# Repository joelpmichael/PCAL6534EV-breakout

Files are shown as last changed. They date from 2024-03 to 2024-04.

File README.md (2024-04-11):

# PCAL6534EV Breakout

## Contents

- [What?](#what)
- [Why?](#why)
- [How?](#how)
- [Can I buy one?](#can-i-buy-one)
- [Can I make one?](#can-i-make-one)
- [Can I make heaps and sell them?](#can-i-make-heaps-and-sell-them)
- [No really, why?](#no-really-why)
- [Board revision history](#board-revision-history)

## What?

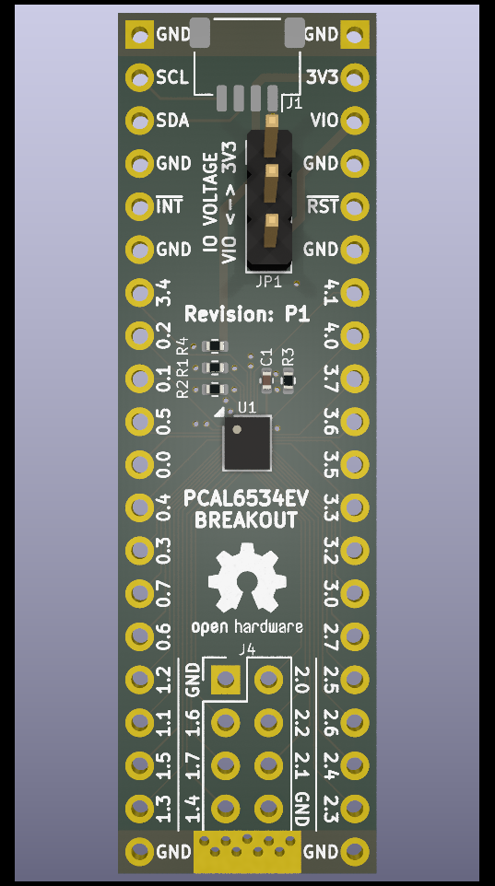
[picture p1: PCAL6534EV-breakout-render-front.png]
3D rendering of PCAL6534EV breakout board front side
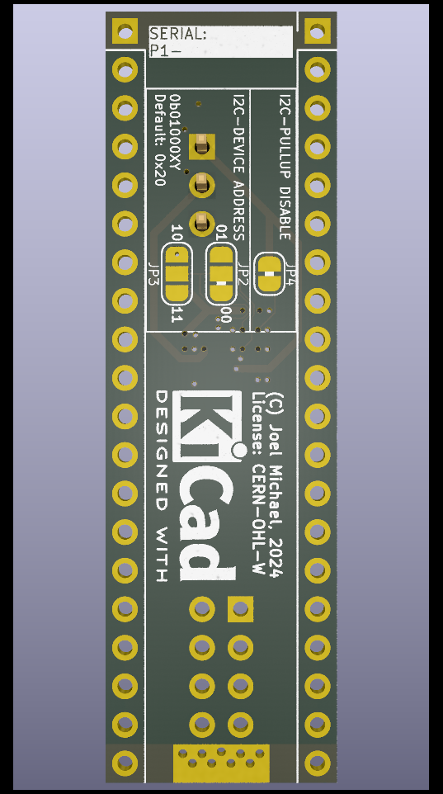
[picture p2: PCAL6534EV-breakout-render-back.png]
3D rendering of PCAL6534EV breakout board back side


This is a breakout board for the [NXP PCAL6534EV I2C GPIO expander](https://www.nxp.com/products/interfaces/ic-spi-i3c-interface-devices/general-purpose-i-o-gpio/ultra-low-voltage-level-translating-34-bit-ic-bus-smbus-i-o-expander:PC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). The board breaks out 32 out of the possible 34 GPIO pins, with 26 of the 32 GPIO pins arranged in a DIP-style layout at 12.7mm column spacing which is perfect for breadboard or protoboard use. There is also a [SparkFun QWIIC-compatible connector](https://www.sparkfun.com/qwiic), for easy connection to other QWIIC-compatible boards.

## Why?

It all started a few years ago, when I was on a holiday in Italy and I found this wonderful little cafe that I stopped at for lunch. I convinced the chef to give me his secret recipe, which he did on one condition: I'm not allowed to tell anybody else until the day I die.

I'm still well and truly alive despite all reports to the contrary, and despite the lack of sleep (#DadLife), so I'm not going to tell you, instead I'm going to make this breakout board instead.

## How?

Please refer to the [PCAL6534EV Datasheet](https://www.nxp.com/docs/en/data-sheet/PCAL6534.pdf) and the [Board Schematic](PCAL6534EV-breakout.pdf) for further details.

- [Connecting](#connecting)
- [Powering](#powering)
- [I2C communication](#i2c-communication)
- [Interrupt and reset](#interrupt-and-reset)
- [GPIO use](#gpio-use)
- [Mounting](#mounting)

### Connecting

Solder the 20-pin headers into each side and slam it into a breadboard! The width is minimised to allow access to 3 pins on each side - wider breakout and prototype boards have always annoyed me by only allowing access to 1 or 2 pins on each side.

Use the QWIIC-compatible connector J1 to connect to your MCU, as the PCAL6534EV is optimised to run at 3.3V. You may run into current supply limits when using the very thin 28AWG wire in QWIIC-compatible cables, as the PCAL6534EV can source up to 450mA or sink up to 500mA of current. If you're driving a lot of LEDs or something, hook up an additional 3.3V power connection to the pin header, and maybe a chonky electrolytic capacitor across 3V3 or VIO.

You can also solder wires directly to the pin headers if needed, or solder the pin headers to a protoboard, or just do what you want I'm not your mum.

At the very bottom edge of the breakout board is an exposed ground plane, designed for you to attach an alligator clip while probing with a multimeter, osciloscope, or logic analyzer.

### Powering

The PCAL6534EV requires 2 power supplies, VDD(i2c) and VDD(p). VDD(i2c) is wired to the 3V3 rail, and must be in the range of 0.8 to 3.6V, allowing you to use lower voltage MCU or FPGA I2C lines. VDD(p) is wired to jumper JP1, and must be in the range of 1.65 to 5.5V. Jumper JP1 selects the source rail of VDD(p), either 3V3 or VIO. When jumper JP1 is set to 3V3, the 3V3 input voltage range is narrowed to 1.65 to 3.6V. When jumper JP1 is set to VIO, the desired IO voltage must be supplied on the VIO pin.

### I2C communication

The PCAL6534EV supports I2C standard-mode at up to 100kHz, fast-mode at up to 400kHz, or fast-mode plus at up to 1000kHz. The breakout board contains 4.7kΩ pull-up resistors from I2C SDA and SCL lines to the 3V3 rail. These pull-up resistors can be disabled by cutting the PCB trace jumper JP4 on the back of the breakout board.

The PCAL6534EV I2C device address is set by connecting the ADDR line to either SDA, SCL, VSS (ground), or VDD(i2c), with a base 7-bit I2C device address of `0b0100000` (`0x20`). The breakout board defaults to the base address `0x20`, and by cutting and bridging PCB jumper pins on JP2 and JP3 can set the device address to `0x20`, `0x21`, `0x22`, or `0x23` according to the following table:

|Jumper|Pins|Address|
|---|----|---|
|JP2|1-2|0x20|
|JP2|2-3|0x21|
|JP3|1-2|0x22|
|JP3|2-3|0x23|

> ⚠️ SDA and SCL pins **ARE NOT** 5V-tolerant!

### Interrupt and reset

The PCAL6534EV contains both an Interrupt (IRQ) line, and a Reset (RST) line. Both lines are active-low. The IRQ output line uses an open-drain driver, and the breakout board contains a 10kΩ pull-up resistor to VDD(i2c) because most likely you'll be using the IRQ signal on the same MCU that the I2C controller is running on. If you really really really REALLY need to change this, you can remove R4 and connect another pull-up resistor between R4 pad 1 (closest to JP4) and VIO, ensuring that VIO is limited to 3.3V.

The Reset input line is an active-low input, and the breakout board contains a a 10kΩ pull-up resistor to VDD(i2c) because most likely you'll be supplying the Reset signal from the same MCU that the I2C controller is running on, or you've wired the Reset line to an external momentary switch and you don't care about the voltage. If you're using a momentary switch, add a 0.1µF capacitor in parallel to the switch for a hardware debouncer and noise filter. It is safe to leave the Reset line disconnected from the breakout board.

> ⚠️ Interrupt and Reset pins **ARE NOT** 5V-tolerant!

### GPIO use

It's a... uh... low-speed GPIO? Just use them, the default PCAL6534EV configuration should work for most cases! All the GPIO pins are 5V-tolerant, and will even produce 5V output if you're using 5V on VIO, so feel free to hook them up to your old MEGA328P-based Arduinos and do voltage level translation. You can even drive a LOT of LEDs directly from the GPIO pins - every pin is recommended to source 10mA or sink 25mA of current, with a combined total of 450mA of sourcing current and 500mA of sinking current.

For advanced use-cases, such as enabling internal 100kΩ pull-up or pull-down resistors, switching between push-pull or open-drain output mode, enabling interrupt generation, enabling debouncing filters, or reducing the drive strength to limit GPIO switching noise, please refer to the datasheet and the example source code.

> ✔️ GPIO pins **ARE** 5V-tolerant!

### Mounting

Due to asthetics and space constraints there isn't enough room for a full-size mounting hole, however in the middle of the OSHW logo there is a 1mm pilot hole that you can use to drill a mounting hole. Ideal? No. Pragmatic? Yes. 

Personally I wouldn't drill a hole larger than 3mm, which will allow you to use a M3 fastener, but you should be able drill up to a 5mm hole without hitting traces. If using metal fasteners, use nylon washers to avoid damage to traces by screw heads.

## Can I buy one?

Sure! Once I've got enough requests for a small batch run I'll send off an order. I test every single board to make sure it's fully functional before shipping.

## Can I make one?

Sure, why not? The board is designed to be manufactured using JLCPCB's 6-layer fabrication constraints as at March 2024 by using budget-size 50mm maximum dimension, budget 0.3mm drill size, 0.8mm thickness, 1oz outer copper, 0.5oz inner copper, and the budget (but surprisingly good) JLC06081H-1080A stackup. It currently does not meet OSHPARK fabrication constraints, as the trace and space minimum of 0.09mm is smaller than the required 0.1mm and there is some via-in-pad use which is currently unsupported.

## Can I make heaps and sell them?

Technically yes, but I'd love it if you gave me a cut in exchange for the testing system that I've developed.

## No really, why?

I wanted to use this GPIO expander in another project, and making a breakout board was probably the best way to verify if my layout hacks would work at all.

Also, shits and giggles: seeing who's both willing and able to manufacture the boards.

## Board Revision History

- [P1](#p1-prototype-1)

### P1: Prototype 1

First prototype, for testing if this even works at all

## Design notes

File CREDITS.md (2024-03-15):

# Credits And Thanks

Thank you to the following people for their help in bringing this idiot idea to life!

## Inspiration and hacks

### Andrew Zonenberg ([Fediverse](https://ioc.exchange/@azonenberg)) ([GitHub](https://github.com/azonenberg))

Thank you for getting me interested in doing my first FPGA design, which lead to me looking at the PCAL6534EV in the first place for power supply sequencing (this is a hint of my next project). Your mention of squashing BGA lands is the hack I'm trying here so I don't need to spend crazy amounts of money on 0.1mm laser vias.

## Prototype reviewers

(none yet)

## Prototype testers

(none yet)

## Contributors

(none yet)

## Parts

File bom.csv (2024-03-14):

Reference | Value | Datasheet | Footprint | Qty | DNP
C1 | 0.22u | ~ | Capacitor_SMD:C_0402_1005Metric | 1
J1 | SM04B-SRSS-TB | ~ | Connector_JST:JST_SH_SM04B-SRSS-TB_1x04-1MP_P1.00mm_Horizontal | 1
J2,J3 | Conn_01x20 | ~ | Connector_PinHeader_2.54mm:PinHeader_1x20_P2.54mm_Vertical | 2 | DNP
J4 | Conn_02x04_Odd_Even | ~ | Connector_PinHeader_2.54mm:PinHeader_2x04_P2.54mm_Vertical | 1 | DNP
JP1 | Jumper_3_Bridged12 | ~ | Connector_PinHeader_2.54mm:PinHeader_1x03_P2.54mm_Vertical | 1
R1,R2 | 4.7k | ~ | Resistor_SMD:R_0402_1005Metric | 2
R3,R4 | 10k | ~ | Resistor_SMD:R_0402_1005Metric | 2
U1 | PCAL6534EV | https://www.nxp.com/docs/en/data-sheet/PCAL6534.pdf | Package_BGA:NXP_VFBGA-42_2.6x3mm_Layout6x7_P0.4mm_Ball0.25mm_Pad0.24mm | 1

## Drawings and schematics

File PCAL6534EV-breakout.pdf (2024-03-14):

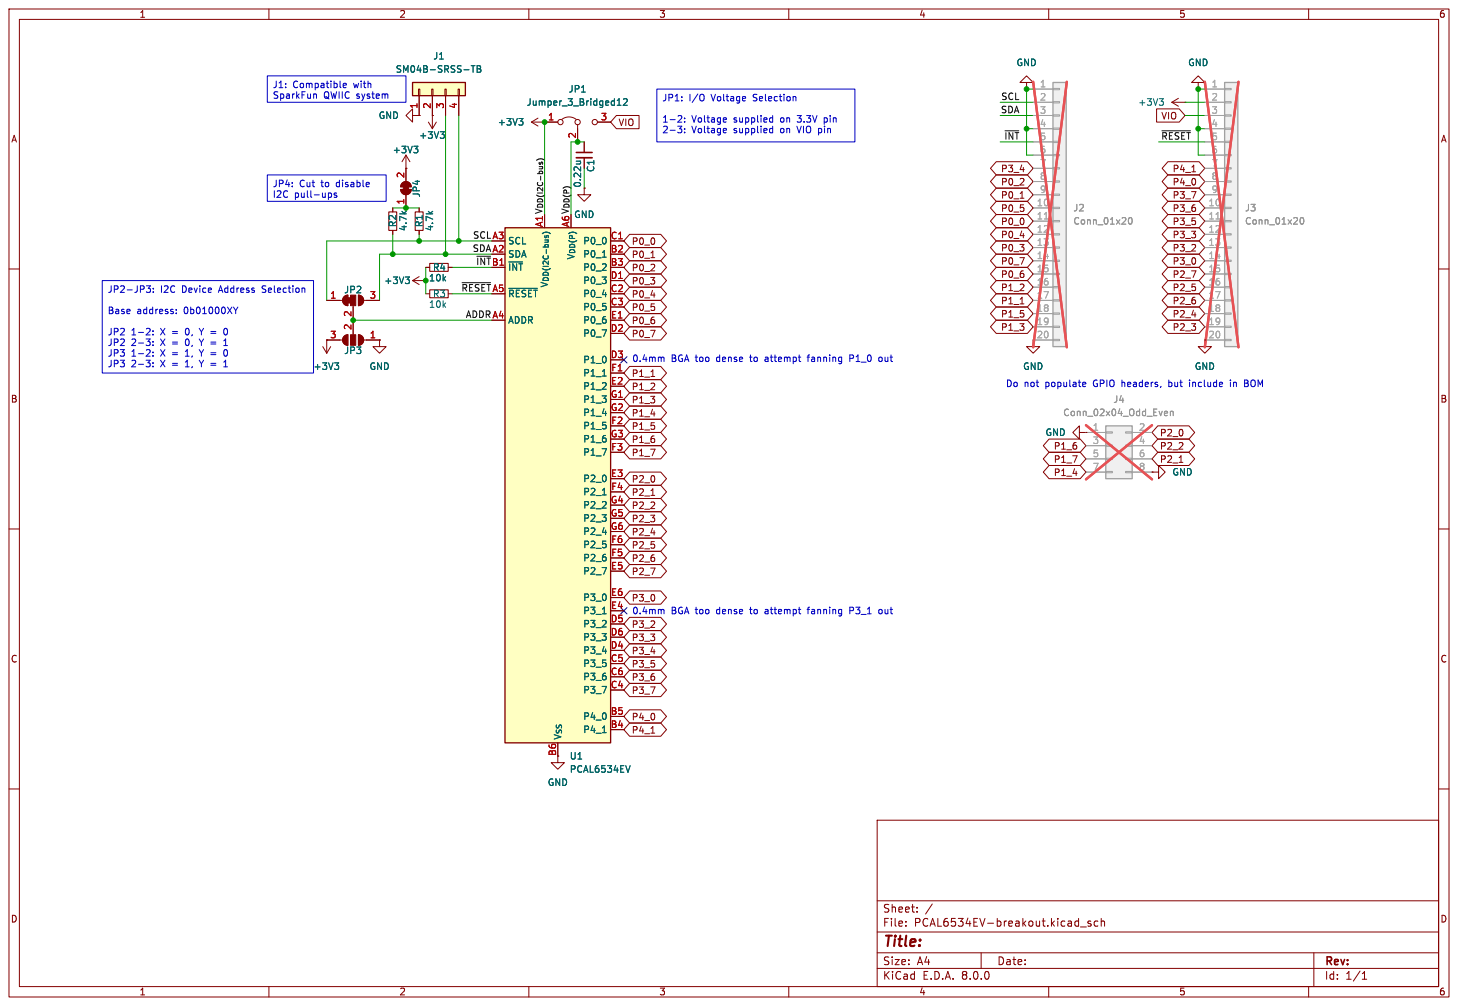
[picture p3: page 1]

Id: 1/1 Title: File: PCAL6534EV-breakout.kicad_sch Sheet: /

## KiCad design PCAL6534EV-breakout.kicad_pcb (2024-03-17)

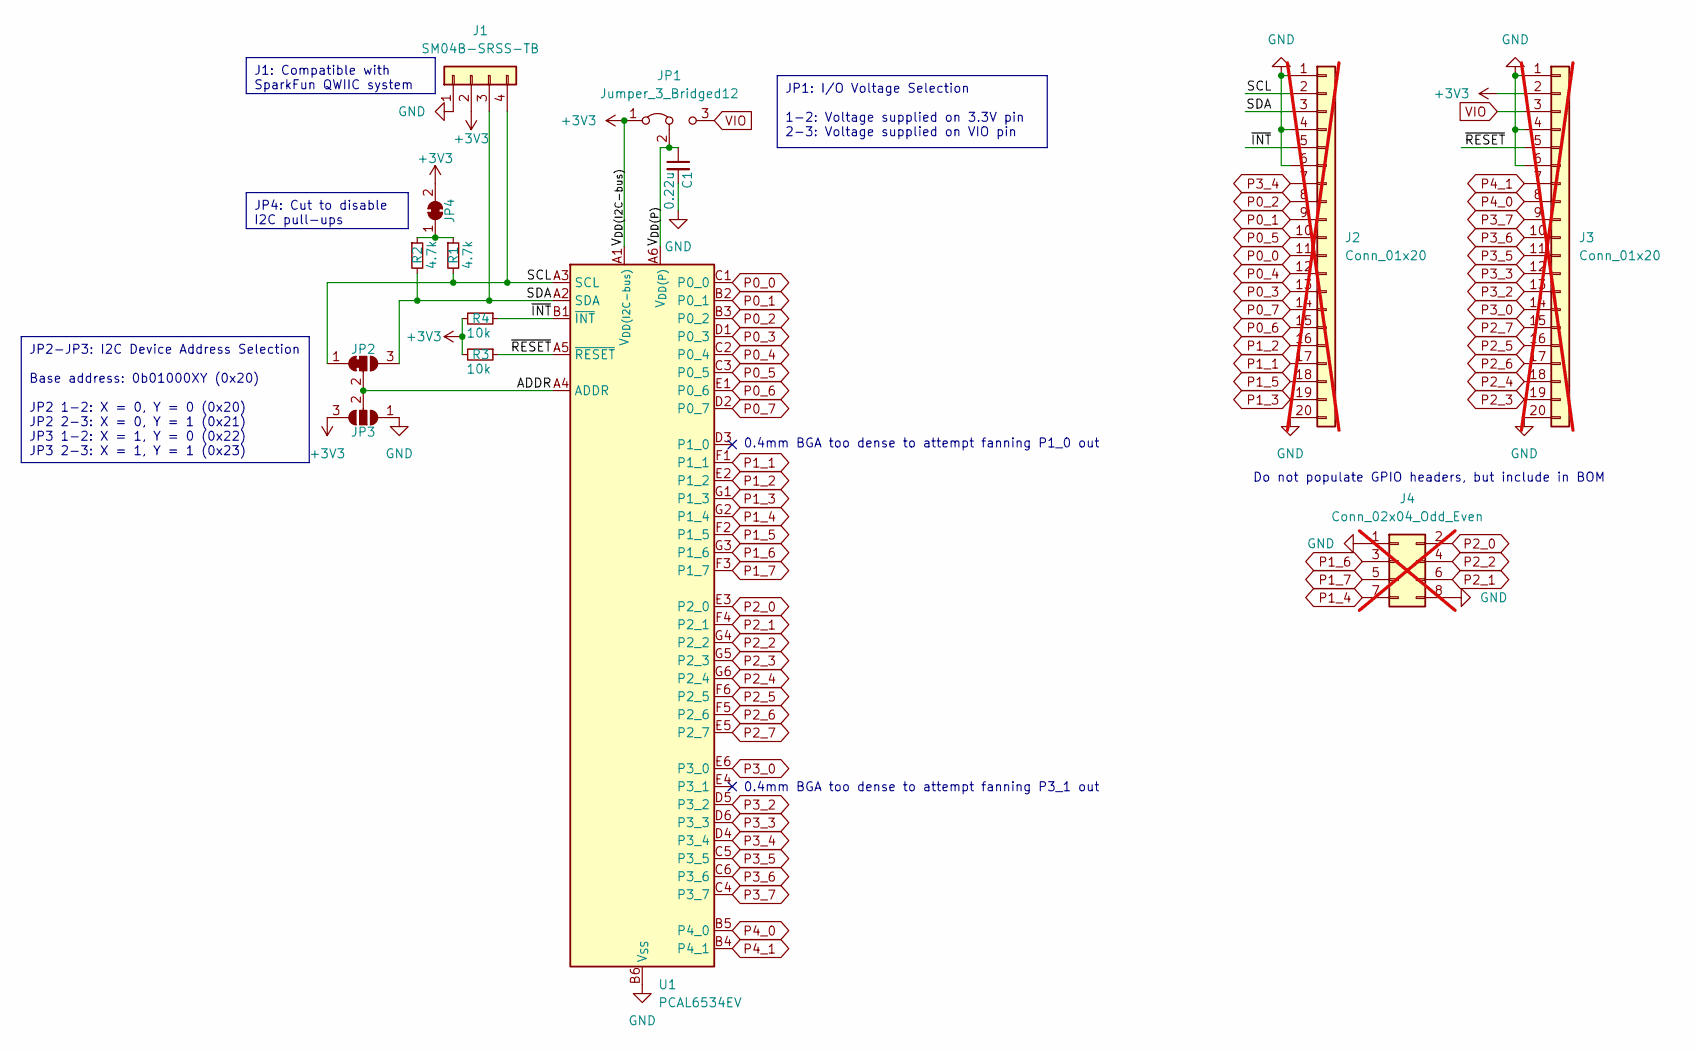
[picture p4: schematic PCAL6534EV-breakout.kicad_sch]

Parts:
C1: 0.22u; C_0402_1005Metric
J1: SM04B-SRSS-TB; JST_SH_SM04B-SRSS-TB_1x04-1MP_P1.00mm_Horizontal
J2, J3: Conn_01x20; PinHeader_1x20_P2.54mm_Vertical; not fitted
J4: Conn_02x04_Odd_Even; PinHeader_2x04_P2.54mm_Vertical; not fitted
JP1: Jumper_3_Bridged12; PinHeader_1x03_P2.54mm_Vertical
JP2: SolderJumper_3_Bridged12; SolderJumper-3_P1.3mm_Bridged12_RoundedPad1.0x1.5mm_NumberL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
JP3: SolderJumper_3_Open; SolderJumper-3_P1.3mm_Open_RoundedPad1.0x1.5mm_NumberLabels
JP4: SolderJumper_2_Bridged; SolderJumper-2_P1.3mm_Bridged_RoundedPad1.0x1.5mm
R1, R2: 4.7k; R_0402_1005Metric
R3, R4: 10k; R_0402_1005Metric
U1: PCAL6534EV; NXP_VFBGA-42_2.6x3mm_Layout6x7_P0.4mm_Ball0.25mm_Pad0.24mm

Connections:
+3V3: J1.2, J3.2, JP1.1 (A), JP3.3 (B), JP4.2 (B), R3.2, R4.2, U1.A1 (V_{DD(I2C-bus)})
/ADDR: JP2.2 (C), JP3.2 (C), U1.A4 (ADDR)
/SCL: J1.4, J2.2, JP2.1 (A), R1.2, U1.A3 (SCL)
/SDA: J1.3, J2.3, JP2.3 (B), R2.2, U1.A2 (SDA)
/V_{DD(P)}: C1.1, JP1.2 (C), U1.A6 (V_{DD(P)})
/~INT: J2.5, R4.1, U1.B1 (~INT)
/~RESET: J3.5, R3.1, U1.A5 (~RESET)
GND: C1.2, J1.1, J1.MP, J2.1, J2.4, J2.6, J2.20, J3.1, J3.4, J3.6, J3.20, J4.1, J4.8, JP3.1 (A), U1.B6 (V_{SS})
unnamed: JP4.1 (A), R1.1, R2.1
P0_0: J2.11, U1.C1 (P0_0)
P0_1: J2.9, U1.B2 (P0_1)
P0_2: J2.8, U1.B3 (P0_2)
P0_3: J2.13, U1.D1 (P0_3)
P0_4: J2.12, U1.C2 (P0_4)
P0_5: J2.10, U1.C3 (P0_5)
P0_6: J2.15, U1.E1 (P0_6)
P0_7: J2.14, U1.D2 (P0_7)
P1_1: J2.17, U1.F1 (P1_1)
P1_2: J2.16, U1.E2 (P1_2)
P1_3: J2.19, U1.G1 (P1_3)
P1_4: J4.7, U1.G2 (P1_4)
P1_5: J2.18, U1.F2 (P1_5)
P1_6: J4.3, U1.G3 (P1_6)
P1_7: J4.5, U1.F3 (P1_7)
P2_0: J4.2, U1.E3 (P2_0)
P2_1: J4.6, U1.F4 (P2_1)
P2_2: J4.4, U1.G4 (P2_2)
P2_3: J3.19, U1.G5 (P2_3)
P2_4: J3.18, U1.G6 (P2_4)
P2_5: J3.16, U1.F6 (P2_5)
P2_6: J3.17, U1.F5 (P2_6)
P2_7: J3.15, U1.E5 (P2_7)
P3_0: J3.14, U1.E6 (P3_0)
P3_2: J3.13, U1.D5 (P3_2)
P3_3: J3.12, U1.D6 (P3_3)
P3_4: J2.7, U1.D4 (P3_4)
P3_5: J3.11, U1.C5 (P3_5)
P3_6: J3.10, U1.C6 (P3_6)
P3_7: J3.9, U1.C4 (P3_7)
P4_0: J3.8, U1.B5 (P4_0)
P4_1: J3.7, U1.B4 (P4_1)
VIO: J3.3, JP1.3 (B)

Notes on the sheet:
JP1: I/O Voltage Selection 1-2: Voltage supplied on 3.3V pin 2-3: Voltage supplied on VIO pin
J1: Compatible with SparkFun QWIIC system
JP4: Cut to disable I2C pull-ups
JP2-JP3: I2C Device Address Selection Base address: 0b01000XY (0x20) JP2 1-2: X = 0, Y = 0 (0x20) JP2 2-3: X = 0, Y = 1 (0x21) JP3 1-2: X = 1, Y = 0 (0x22) JP3 2-3: X = 1, Y = 1 (0x23)
0.4mm BGA too dense to attempt fanning P3_1 out
Do not populate GPIO headers, but include in BOM
0.4mm BGA too dense to attempt fanning P1_0 out

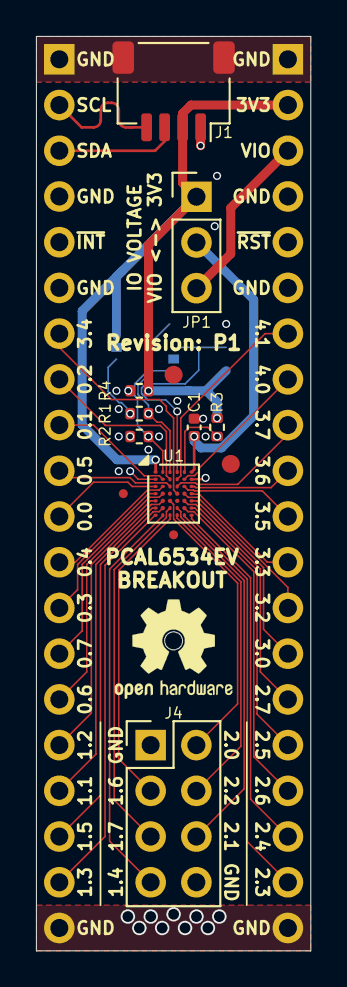
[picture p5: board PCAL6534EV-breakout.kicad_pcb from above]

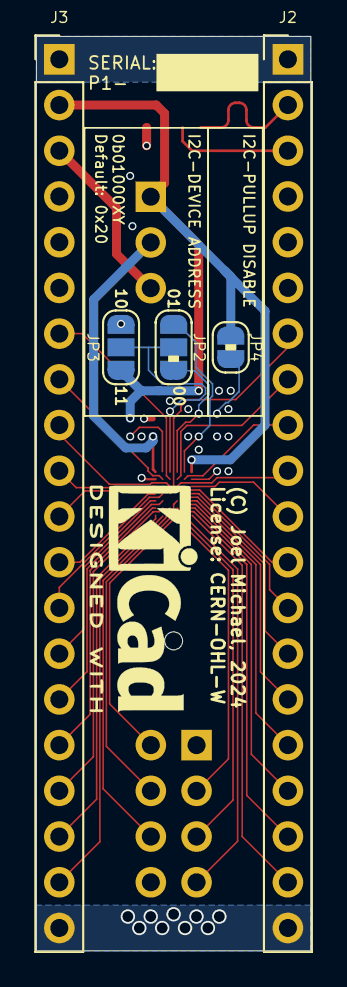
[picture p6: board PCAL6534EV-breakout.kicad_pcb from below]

Board: 6 copper layers, 15.2 x 50.8 mm, 18 parts (5 on the bottom side), 42 nets.

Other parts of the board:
FID1, FID2: Fiducial_0.5mm_Mask1mm
FID3, FID4: Fiducial_1mm_Mask2mm

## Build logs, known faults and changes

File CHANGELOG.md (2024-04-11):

# Change / Development Log

## Hardware prototype 2

### Fixes

* Connect MP pins of J1 to GND strip across the top edge of the board

## Driver release 1

TODO

## Hardware prototype 1

### 5 April 2023

First prototype run of boards arrived. Issue identified where MP on J1 was not connected to the GND strip across the top edge of the board, which would compromise strength of J1 and possibly lead to J1 being ripped off the board under mechanical stress.

### Serial 1

Used a LOT of flux and SnBi low-temperature solder on a hotplate. Solder reflow worked ok (not great, but not unusable), but would probably work better using less solder and/or an actual stencil.  Shorts between the following pins:

* P0_0 - P0_3
* P1_2 - P2_0
* P3_0 - P2_5
* P2_7 - P2_6

Pin headers added using SnPb 60/40 solder.

Communication established using Excamera I2Cdriver board. Verified all GPIOs can be changed from hi-z inputs to push-pull outputs. Verified all GPIOs are connected, and show both 3.3V and 0V levels when output level is set. Verified LED using current-sinking on P4_1.

### Serial 2

TODO

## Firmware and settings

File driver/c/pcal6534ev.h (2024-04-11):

/*
 *
 * PCAL6534EV driver - C example
 *
 * Full datasheet at https://www.nxp.com/docs/en/data-sheet/PCAL6534.pdf
 *
 */

// required includes
#include <stddef.h>
#include <stdint.h>

// Common definitions

// Function return codes
typedef enum pcal6534ev_status_e {
    PCAL6534EV_STATUS_OK = 0,
    PCAL6534EV_STATUS_FAIL = 0,
} pcal6534ev_status;

// Register names
typedef enum pcal6534ev_register_e {
    PCAL6534EV_REG_INPUT_PORT_0 = 0x00,
    PCAL6534EV_REG_INPUT_PORT_1 = 0x01,
    PCAL6534EV_REG_INPUT_PORT_2 = 0x02,
    PCAL6534EV_REG_INPUT_PORT_3 = 0x03,
    PCAL6534EV_REG_INPUT_PORT_4 = 0x04,

    PCAL6534EV_REG_OUTPUT_PORT_0 = 0x05,
    PCAL6534EV_REG_OUTPUT_PORT_1 = 0x06,
    PCAL6534EV_REG_OUTPUT_PORT_2 = 0x07,
    PCAL6534EV_REG_OUTPUT_PORT_3 = 0x08,
    PCAL6534EV_REG_OUTPUT_PORT_4 = 0x09,

    PCAL6534EV_REG_POLINV_PORT_0 = 0x0A,
    PCAL6534EV_REG_POLINV_PORT_1 = 0x0B,
    PCAL6534EV_REG_POLINV_PORT_2 = 0x0C,
    PCAL6534EV_REG_POLINV_PORT_3 = 0x0D,
    PCAL6534EV_REG_POLINV_PORT_4 = 0x0E,

    PCAL6534EV_REG_CONFIG_PORT_0 = 0x0F,
    PCAL6534EV_REG_CONFIG_PORT_1 = 0x10,
    PCAL6534EV_REG_CONFIG_PORT_2 = 0x11,
    PCAL6534EV_REG_CONFIG_PORT_3 = 0x12,
    PCAL6534EV_REG_CONFIG_PORT_4 = 0x13,

    PCAL6534EV_REG_DRIVE_PORT_0A = 0x30,
    PCAL6534EV_REG_DRIVE_PORT_0B = 0x31,
    PCAL6534EV_REG_DRIVE_PORT_1A = 0x32,
    PCAL6534EV_REG_DRIVE_PORT_1B = 0x33,
    PCAL6534EV_REG_DRIVE_PORT_2A = 0x34,
    PCAL6534EV_REG_DRIVE_PORT_2B = 0x35,
    PCAL6534EV_REG_DRIVE_PORT_3A = 0x36,
    PCAL6534EV_REG_DRIVE_PORT_3B = 0x37,
    PCAL6534EV_REG_DRIVE_PORT_4A = 0x38,

    PCAL6534EV_REG_ILATCH_PORT_0 = 0x3A,
    PCAL6534EV_REG_ILATCH_PORT_1 = 0x3B,
    PCAL6534EV_REG_ILATCH_PORT_2 = 0x3C,
    PCAL6534EV_REG_ILATCH_PORT_3 = 0x3D,
    PCAL6534EV_REG_ILATCH_PORT_4 = 0x3E,

    PCAL6534EV_REG_PULLEN_PORT_0 = 0x3F,
    PCAL6534EV_REG_PULLEN_PORT_1 = 0x40,
    PCAL6534EV_REG_PULLEN_PORT_2 = 0x41,
    PCAL6534EV_REG_PULLEN_PORT_3 = 0x42,
    PCAL6534EV_REG_PULLEN_PORT_4 = 0x43,

    PCAL6534EV_REG_PULLDIR_PORT_0 = 0x44,
    PCAL6534EV_REG_PULLDIR_PORT_1 = 0x45,
    PCAL6534EV_REG_PULLDIR_PORT_2 = 0x46,
    PCAL6534EV_REG_PULLDIR_PORT_3 = 0x47,
    PCAL6534EV_REG_PULLDIR_PORT_4 = 0x48,

    PCAL6534EV_REG_IMASK_PORT_0 = 0x49,
    PCAL6534EV_REG_IMASK_PORT_1 = 0x4A,
    PCAL6534EV_REG_IMASK_PORT_2 = 0x4B,
    PCAL6534EV_REG_IMASK_PORT_3 = 0x4C,
    PCAL6534EV_REG_IMASK_PORT_4 = 0x4D,

    PCAL6534EV_REG_ISTAT_PORT_0 = 0x4E,
    PCAL6534EV_REG_ISTAT_PORT_1 = 0x4F,
    PCAL6534EV_REG_ISTAT_PORT_2 = 0x50,
    PCAL6534EV_REG_ISTAT_PORT_3 = 0x51,
    PCAL6534EV_REG_ISTAT_PORT_4 = 0x52,

    PCAL6534EV_REG_OUT_PORT_CFG = 0x53,

    PCAL6534EV_REG_IEDGE_PORT_0A = 0x54,
    PCAL6534EV_REG_IEDGE_PORT_0B = 0x55,
    PCAL6534EV_REG_IEDGE_PORT_1A = 0x56,
    PCAL6534EV_REG_IEDGE_PORT_1B = 0x57,
    PCAL6534EV_REG_IEDGE_PORT_2A = 0x58,
    PCAL6534EV_REG_IEDGE_PORT_2B = 0x59,
    PCAL6534EV_REG_IEDGE_PORT_3A = 0x5A,
    PCAL6534EV_REG_IEDGE_PORT_3B = 0x5B,
    PCAL6534EV_REG_IEDGE_PORT_4A = 0x5C,

    PCAL6534EV_REG_ICLR_PORT_0 = 0x5E,
    PCAL6534EV_REG_ICLR_PORT_1 = 0x5F,
    PCAL6534EV_REG_ICLR_PORT_2 = 0x60,
    PCAL6534EV_REG_ICLR_PORT_3 = 0x61,
    PCAL6534EV_REG_ICLR_PORT_4 = 0x62,

    PCAL6534EV_REG_INPUT_STAT_PORT_0 = 0x63,
    PCAL6534EV_REG_INPUT_STAT_PORT_1 = 0x64,
    PCAL6534EV_REG_INPUT_STAT_PORT_2 = 0x65,
    PCAL6534EV_REG_INPUT_STAT_PORT_3 = 0x66,
    PCAL6534EV_REG_INPUT_STAT_PORT_4 = 0x67,

    PCAL6534EV_REG_OUT_PIN_PORT_0_CFG = 0x68,
    PCAL6534EV_REG_OUT_PIN_PORT_1_CFG = 0x69,
    PCAL6534EV_REG_OUT_PIN_PORT_2_CFG = 0x6A,
    PCAL6534EV_REG_OUT_PIN_PORT_3_CFG = 0x6B,
    PCAL6534EV_REG_OUT_PIN_PORT_4_CFG = 0x6C,

    PCAL6534EV_REG_DEBOUNCE_ENABLE_PORT_0 = 0x6D,
    PCAL6534EV_REG_DEBOUNCE_ENABLE_PORT_1 = 0x6E,
    PCAL6534EV_REG_DEBOUNCE_COUNT = 0x6F,
} pcal6534ev_register;

// Port names
typedef enum pcal6534ev_port_e {
    PCAL6534EV_PORT_0 = 0,
    PCAL6534EV_PORT_1 = 1,
    PCAL6534EV_PORT_2 = 2,
    PCAL6534EV_PORT_3 = 3,
    PCAL6534EV_PORT_4 = 4,
} pcal6534ev_port;
#define PCAL6534EV_PORT_COUNT 5

// Pin names
typedef enum pcal6534ev_port_pin_e {
    PCAL6534EV_PORT_PIN_0 = 1 << 0,
    PCAL6534EV_PORT_PIN_1 = 1 << 1,
    PCAL6534EV_PORT_PIN_2 = 1 << 2,
    PCAL6534EV_PORT_PIN_3 = 1 << 3,
    PCAL6534EV_PORT_PIN_4 = 1 << 4,
    PCAL6534EV_PORT_PIN_5 = 1 << 5,
    PCAL6534EV_PORT_PIN_6 = 1 << 6,
    PCAL6534EV_PORT_PIN_7 = 1 << 7,
} pcal6534ev_port_pin;
#define PCAL6534EV_PORT_PIN_COUNT 8

// Pin levels
typedef enum pcal6534ev_pin_level_e {
    PCAL6534EV_PIN_LEVEL_LOW = 0,
    PCAL6534EV_PIN_LEVEL_HIGH = 1,
} pcal6534ev_pin_level;

// Pin mode configuration - input (hi-z) or output (push-pull/open-drain)
// All pins are configured as input (hi-z) by default
typedef enum pcal6534ev_pin_mode_e {
    PCAL6534EV_PIN_MODE_OUTPUT = 0,
    PCAL6534EV_PIN_MODE_INPUT = 1,
} pcal6534ev_pin_mode;

// Output pin configuration
typedef enum pcal6534ev_pin_output_mode_e {
    PCAL6534EV_PIN_OUTPUT_MODE_PUSHPULL_NOPULL = 0b00,
    PCAL6534EV_PIN_OUTPUT_MODE_OPENDRAIN = 0b01,
    PCAL6534EV_PIN_OUTPUT_MODE_PUSHPULL_PULLDOWN = 0b10,
    PCAL6534EV_PIN_OUTPUT_MODE_PUSHPULL_PULLUP = 0b11,
} pcal6534ev_pin_output_mode;

// Output pin drive strength
typedef enum pcal6534ev_pin_output_drive_e {
    PCAL6534EV_PIN_OUTPUT_DRIVE_25 = 0b00,
    PCAL6534EV_PIN_OUTPUT_DRIVE_50 = 0b01,
    PCAL6534EV_PIN_OUTPUT_DRIVE_75 = 0b10,
    PCAL6534EV_PIN_OUTPUT_DRIVE_100 = 0b11,
} pcal6534ev_pin_output_drive;

// Input pin configuration

typedef enum pcal6534ev_i2c_address_e {
    I2C_GENERAL_CALL = 0x00,

    // Device Addresses: lower 7 bits
    // Suitable for MCU SDKs that expect I2C device address in the lower 7 bits (eg MCP)
    I2C_DEVICE_ID_L = 0xFE >> 1,
    PCAL6534EV_ADDR_00_L = 0x40 >> 1,
    PCAL6534EV_ADDR_01_L = 0x42 >> 1,
    PCAL6534EV_ADDR_10_L = 0x44 >> 1,
    PCAL6534EV_ADDR_11_L = 0x46 >> 1,

    // Device Addresses: upper 7 bits
    // Suitable for MCU SDKs that expect I2C device address in the upper 7 bits (eg STM32)
    I2C_DEVICE_ID_H = 0xFE,
    PCAL6534EV_ADDR_00_H = 0x40,
    PCAL6534EV_ADDR_01_H = 0x42,
    PCAL6534EV_ADDR_10_H = 0x44,
    PCAL6534EV_ADDR_11_H = 0x46,
} pcal6534ev_i2c_address;

// Device address aliases

// For ease of use when the ADDR pin is connected to a known address-set pin
#define PCAL6534EV_ADDR_SCL_L PCAL6534EV_ADDR_00_L
#define PCAL6534EV_ADDR_SDA_L PCAL6534EV_ADDR_10_L
#define PCAL6534EV_ADDR_VSS_L PCAL6534EV_ADDR_01_L
#define PCAL6534EV_ADDR_VDD_L PCAL6534EV_ADDR_11_L
#define PCAL6534EV_ADDR_SCL_H PCAL6534EV_ADDR_00_H
#define PCAL6534EV_ADDR_SDA_H PCAL6534EV_ADDR_10_H
#define PCAL6534EV_ADDR_VSS_H PCAL6534EV_ADDR_01_H
#define PCAL6534EV_ADDR_VDD_H PCAL6534EV_ADDR_11_H
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

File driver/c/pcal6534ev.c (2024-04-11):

/*
 *
 * PCAL6534EV driver - C example
 *
 * Full datasheet at https://www.nxp.com/docs/en/data-sheet/PCAL6534.pdf
 *
 */

// magic defines that will alter how the PCAL6534EV driver behaves

// Is this a PCAL6534EV breakout board? This disables P1_0 and P3_1
#define PCAL6534EV_BREAKOUT

// Other pins to disable
#define PCAL6534EV_PORT_0_DISABLE_PINS 0b00000000
#define PCAL6534EV_PORT_1_DISABLE_PINS 0b00000000
#define PCAL6534EV_PORT_2_DISABLE_PINS 0b00000000
#define PCAL6534EV_PORT_3_DISABLE_PINS 0b00000000
#define PCAL6534EV_PORT_4_DISABLE_PINS 0b00000000

// Include must come after the defines
#include <pcal6534ev.h>

pcal6534ev_status pcal6534ev_reset_software(pcal6534ev_i2c_write_cb *pcal6534ev_i2c_write_cb) {
}

pcal6534ev_status pcal6534ev_init(
    pcal6534ev *device,
    pcal6534ev_i2c_address i2c_address,
    uint8_t debounce_count,
    pcal6534ev_i2c_read_cb *pcal6534ev_i2c_read_cb,
    pcal6534ev_i2c_write_cb *pcal6534ev_i2c_write_cb,
    pcal6534ev_i2c_read_reg_cb *pcal6534ev_i2c_read_reg_cb,
    pcal6534ev_reset_gpio_cb *pcal6534ev_reset_gpio_cb) {
}

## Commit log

2024-03-14 add pdf of schematic
2024-03-14 add more art
    [PCAL6534EV-breakout.kicad_pcb, PCAL6534EV-breakout.kicad_sch, bom.csv]
2024-03-14 prep outputs for manufacturing
    [PCAL6534EV-breakout-B_Adhesive.gbr, PCAL6534EV-breakout-B_Cu.gbr, PCAL6534EV-breakout-B_Mask.gbr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]
2024-03-15 note to self: run DRC _BEFORE_ exporting
    [PCAL6534EV-breakout-B_Adhesive.gbr, PCAL6534EV-breakout-B_Cu.gbr, PCAL6534EV-breakout-B_Mask.gbr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]
2024-03-15 initial checkin
    [PCAL6534EV-breakout.kicad_sch]
2024-03-15 add fiducials; add pilot hole for drilling a mounting hole
    [PCAL6534EV-breakout.kicad_pcb]
2024-03-15 nudge here, prod there, and pretty soon you've changed the entire thing
    [PCAL6534EV-breakout-B_Adhesive.gbr, PCAL6534EV-breakout-B_Cu.gbr, PCAL6534EV-breakout-B_Mask.gbr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]
2024-03-15 just slam them all in an update again
    [PCAL6534EV-breakout-B_Adhesive.gbr, PCAL6534EV-breakout-B_Cu.gbr, PCAL6534EV-breakout-B_Mask.gbr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]
2024-03-17 nudge BGA tracks around by 0.01mm; length-match I2C SDA and SCL lines
    [PCAL6534EV-breakout-B_Adhesive.gbr, PCAL6534EV-breakout-B_Cu.gbr, PCAL6534EV-breakout-B_Mask.gbr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]
2024-04-11 initial pieces for driver examples

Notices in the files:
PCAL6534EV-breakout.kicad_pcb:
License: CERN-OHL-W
